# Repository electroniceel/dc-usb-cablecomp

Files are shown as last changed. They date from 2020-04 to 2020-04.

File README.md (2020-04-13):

12 VDC to Vusb adapter with compensation for cable resistance
=============================================================

Use a reliable 12 VDC power supply for USB-powered devices.

Dedicated USB chargers often don't have the desired reliability 
for 24/7 use over several years. Power supplies with 12 VDC output
into a DC jack are available in a reliable quality. I can recommend
Meanwell GST40A12-P1J.

USB cables often have higher resistance than
dedicated power cables, even the better ones designed for charging.
This leads to significant voltage drop at higher loads and can cause
the devices to become unstable. Also charging phones is often slower
due to the voltage drop. This adapter compensates for this by sligtly 
increasing the voltage with increasing load.

Schematics & Layout
-------------------

Schematics & Layout were done in KiCAD.

[Schematics as PDF](https://github.com/electroniceel/dc-usb-cablecomp/raw/master/schematics.pdf)

Case
----

I designed the adapter with heatshrink tube as case in mind. I used
heatshrink tube with 24mm unshrunk diameter, hotglue inside and 4:1 shrink ratio.

The label on my heatshrink tube says "PLDW 104-24/6", Reichelt order number "SDK 24,0 SW".

I cut a strip of 42mm, which fits well after shrinking.

License
-------


This work is licensed under a [Creative Commons Attribution 4.0 International License](https://creativecommons.org/licenses/by/4.0/).

Please link to https://github.com/electroniceel/dc-usb-cablecomp or https://git.io/JfeTQ for attribution.

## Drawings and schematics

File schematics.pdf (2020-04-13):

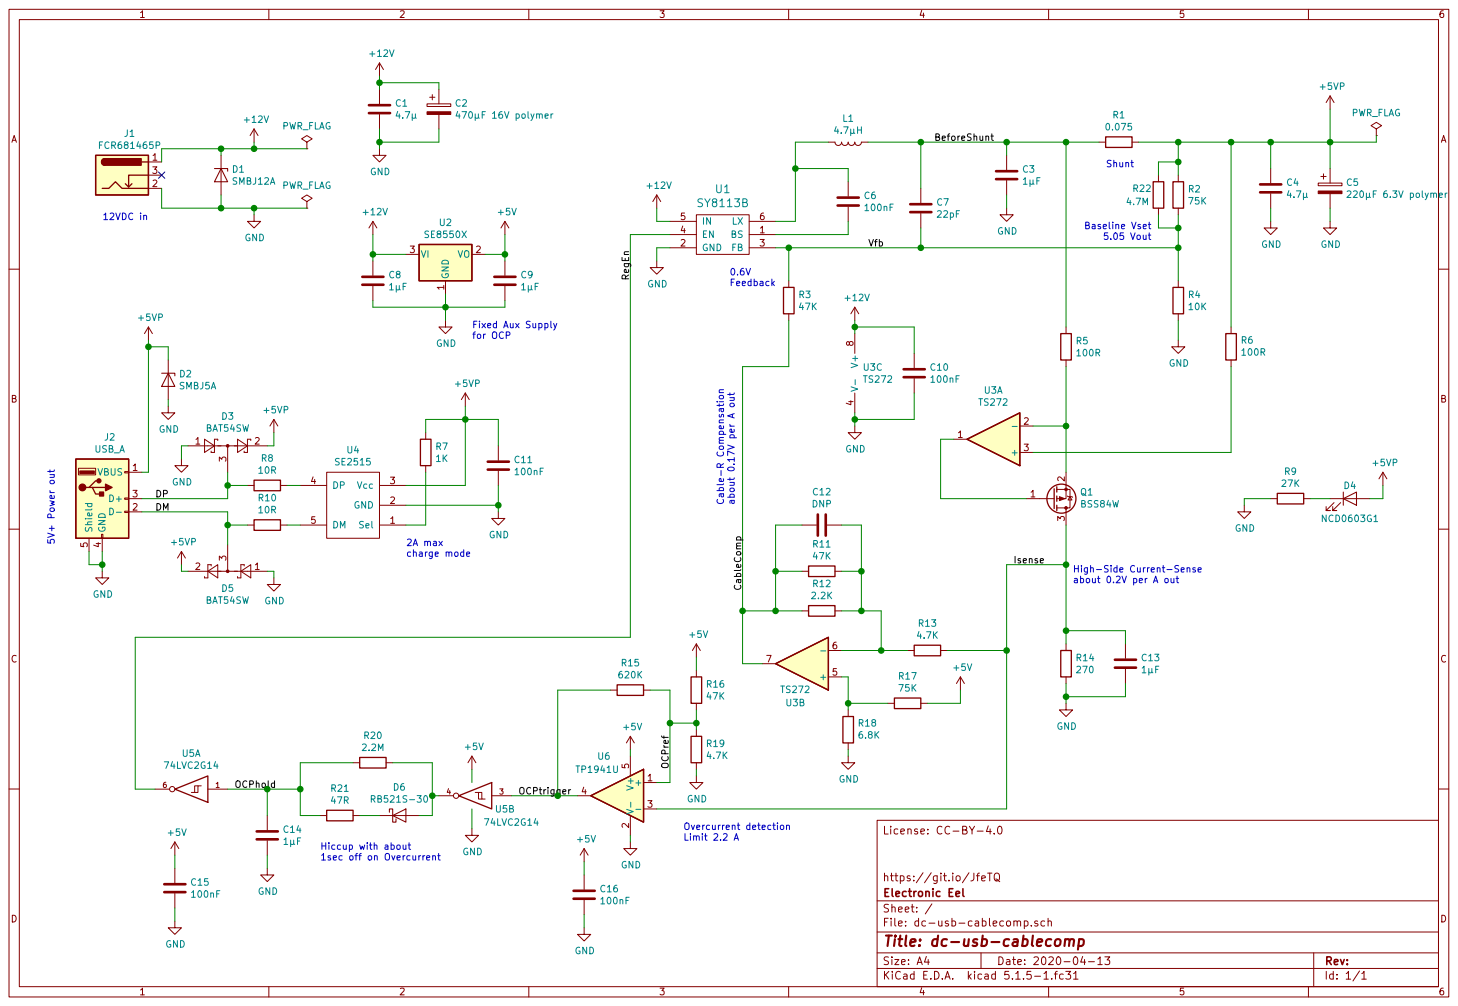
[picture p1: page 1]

about 0.2V per A out Cable-R Compensation about 0.17V per A out Overcurrent detection

Limit 2.2 A Hiccup with about 1sec off on Overcurrent 2A max

File: dc-usb-cablecomp.sch Sheet: / Electronic Eel https://git.io/JfeTQ

Id: 1/1 Title: dc-usb-cablecomp

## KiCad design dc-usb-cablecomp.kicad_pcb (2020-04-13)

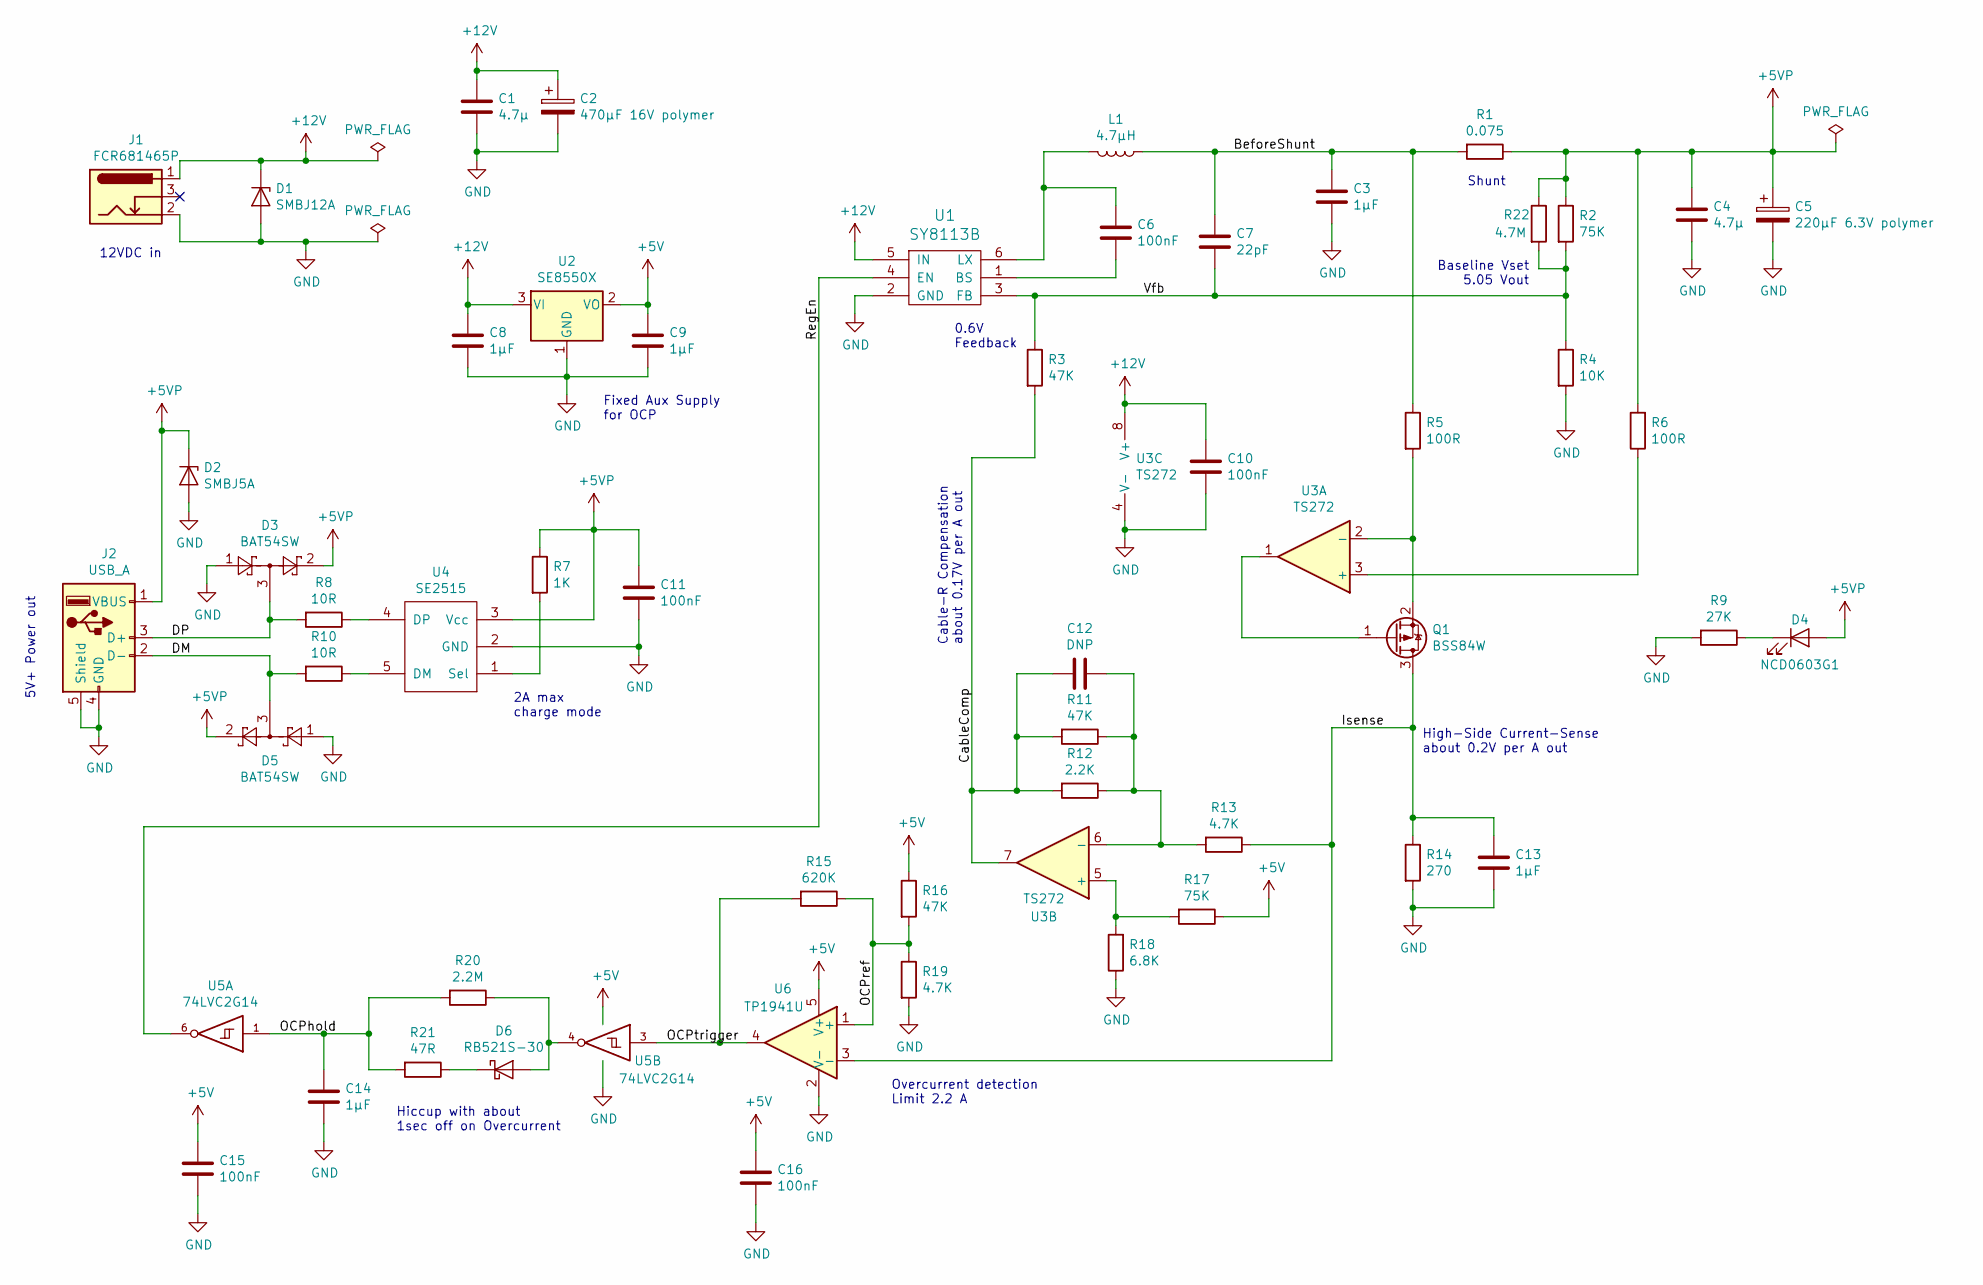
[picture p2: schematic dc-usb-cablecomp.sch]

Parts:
C1, C4: 4.7µ; SMD0805-wide-C
C2: 470µF 16V polymer; C_Radial_D6.3mm_H11.0mm_P2.50mm
C3, C8, C9, C13, C14: 1µF; SMD0603-wide-C
C5: 220µF 6.3V polymer; C_Radial_D5.0mm_H7.0mm_P2.00mm
C6, C10, C11, C15, C16: 100nF; SMD0603-wide-C
C7: 22pF; SMD0603-wide-C
C12: DNP; SMD0603-wide-C
D1: SMBJ12A; SMB_Diode
D2: SMBJ5A; SMB_Diode
D3, D5: BAT54SW; SOT-323-wide
D4: NCD0603G1; SMD0603-wide-diode
D6: RB521S-30; D_SOD-523
J1: FCR681465P; Cliff_FCR681465P_barrel_jack
J2: USB_A
L1: 4.7µH; Fastron-1616FPS
Q1: BSS84W; SOT-323-wide
R1: 0.075; SMD0805-wide-R
R2, R17: 75K; SMD0603-wide-R
R3, R11, R16: 47K; SMD0603-wide-R
R4: 10K; SMD0603-wide-R
R5, R6: 100R; SMD0603-wide-R
R7: 1K; SMD0603-wide-R
R8, R10: 10R; SMD0603-wide-R
R9: 27K; SMD0603-wide-R
R12: 2.2K; SMD0603-wide-R
R13, R19: 4.7K; SMD0603-wide-R
R14: 270; SMD0603-wide-R
R15: 620K; SMD0603-wide-R
R18: 6.8K; SMD0603-wide-R
R20: 2.2M; SMD0603-wide-R
R21: 47R; SMD0603-wide-R
R22: 4.7M; SMD0603-wide-R
U1: SY8113B; SOT-23-6
U2: SE8550X; SOT-23
U3: TS272; TSSOP-8_4.4x3mm_P0.65mm
U4: SE2515; SOT-23-5
U5: 74LVC2G14; SC-70-6-wide
U6: TP1941U; SC-70-5-wide

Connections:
+5V: C9.1, C15.1, C16.1, R16.1, R17.1, U2.2 (VO), U5.5 (VCC), U6.5 (V+)
+5VP: C4.1, C5.1, C11.1, D2.1 (K), D3.2, D4.2 (A), D5.2, J2.1 (VBUS), R1.1, R2.1, R6.2, R7.1, R22.1, U4.3 (Vcc)
+12V: C1.1, C2.1, C8.1, C10.1, D1.1 (K), J1.1, U1.5 (IN), U2.3 (VI), U3.8 (V+)
/BeforeShunt: C3.1, C7.1, L1.1, R1.2, R5.1
/CableComp: C12.2, R3.2, R11.2, R12.2, U3.7
/DM: D5.3, J2.2 (D-), R10.2
/DP: D3.3, J2.3 (D+), R8.2
/Isense: C13.1, Q1.3 (D), R13.1, R14.1, U6.3 (-)
/OCPhold: C14.1, R20.2, R21.2, U5.1
/OCPref: R15.1, R16.2, R19.1, U6.1 (+)
/OCPtrigger: R15.2, U5.3, U6.4
/RegEn: U1.4 (EN), U5.6
/Vfb: C7.2, R2.2, R3.1, R4.1, R22.2, U1.3 (FB)
GND: C1.2, C2.2, C3.2, C4.2, C5.2, C8.2, C9.2, C10.2, C11.2, C13.2, C14.2, C15.2, C16.2, D1.2 (A), D2.2 (A), D3.1, D5.1, J1.2, J2.4 (GND), J2.5 (Shield), R4.2, R9.2, R14.2, R18.1, R19.2, U1.2 (GND), U2.1 (GND), U3.4 (V-), U4.2 (GND), U5.2 (GND), U6.2 (V-)
unnamed: C6.1, L1.2, U1.6 (LX)
unnamed: C6.2, U1.1 (BS)
unnamed: C12.1, R11.1, R12.1, R13.2, U3.6 (-)
unnamed: D4.1 (K), R9.1
unnamed: D6.1 (K), R21.1
unnamed: D6.2 (A), R20.1, U5.4
unnamed: Q1.1 (G), U3.1
unnamed: Q1.2 (S), R5.2, U3.2 (-)
unnamed: R6.1, U3.3 (+)
unnamed: R7.2, U4.1 (Sel)
unnamed: R8.1, U4.4 (DP)
unnamed: R10.1, U4.5 (DM)
unnamed: R17.2, R18.2, U3.5 (+)

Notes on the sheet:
High-Side Current-Sense about 0.2V per A out
Shunt
Cable-R Compensation about 0.17V per A out
Baseline Vset 5.05 Vout
Overcurrent detection Limit 2.2 A
Hiccup with about 1sec off on Overcurrent
0.6V Feedback
2A max charge mode
12VDC in
5V+ Power out
Fixed Aux Supply for OCP

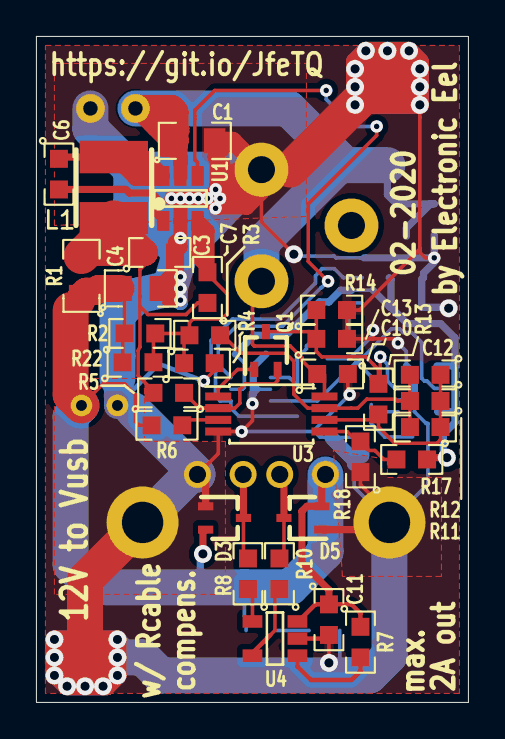
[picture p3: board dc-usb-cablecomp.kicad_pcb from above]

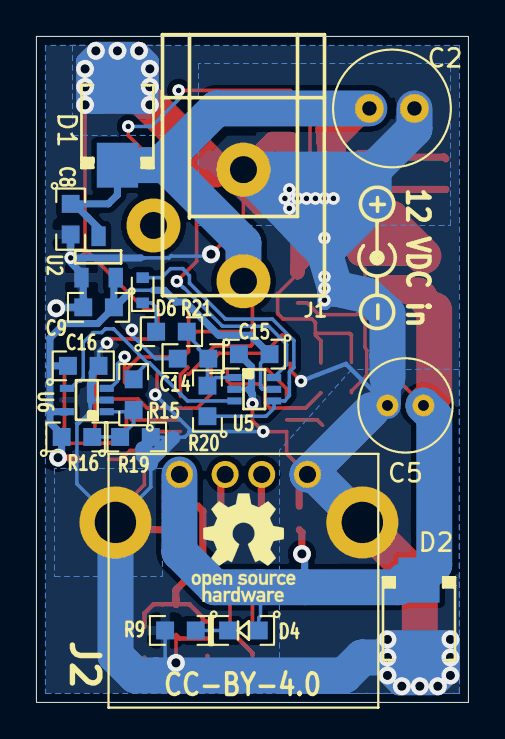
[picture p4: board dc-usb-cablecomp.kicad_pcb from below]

Board: 2 copper layers, 24.0 x 37.0 mm, 54 parts (22 on the bottom side), 27 nets.

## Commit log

2020-04-13 Kicad project data dump
    [dc-usb-cablecomp.kicad_pcb, dc-usb-cablecomp.sch]
2020-04-13 add note about heatshrink case
2020-04-13 add schematics as pdf
    [dc-usb-cablecomp.sch]

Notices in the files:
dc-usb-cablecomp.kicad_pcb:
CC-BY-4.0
